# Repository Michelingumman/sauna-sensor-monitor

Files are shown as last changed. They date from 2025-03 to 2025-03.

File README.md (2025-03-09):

# 🔥 Sauna Monitoring System with ESP32




A smart monitoring system that tracks temperature and humidity in saunas, detects sessions automatically, and provides real-time visualization through an OLED display and optional web interface.

Custom PCB Board

## 🔍 Overview

This ESP32-based system provides comprehensive monitoring for saunas, automatically detecting when sessions begin and end based on temperature changes. The device displays real-time data on an OLED screen and can optionally connect to Blynk for remote monitoring.

## ✨ Features

### Time Synchronization
- Automatically syncs with NTP servers for accurate time display
- Shows current time in format: `Monday 01-13:00`

### Intelligent Session Detection
- Automatically detects sauna sessions when temperature rises from 20°C to 30°C within 15 minutes
- Tracks session duration and highest temperature
- Detects session end when temperature drops to 30% of peak temperature

### Real-time Monitoring
- Updates temperature and humidity readings every 2 seconds
- Shows current readings with icons
- Sauna Session active indicator

### Connectivity
- Wi-Fi connectivity for time synchronization
- Built-in web server with real-time dashboard
- OTA (Over-the-Air) update capability

## 🛠️ Hardware Requirements

### Components
- **ESP32 Development Board**: Any standard ESP32 board
- **SSD1306 OLED Display**: I2C interface
- **SHT2x Temperature/Humidity Sensor**: I2C interface

### Connections
| Component | ESP32 Pin |
|---|---|
| OLED SDA  | GPIO 6 |
| OLED SCL  | GPIO 7 |
| SHT2x | Same I2C bus |
| Power | 3.3V |

## 💻 Software Requirements

### Development Environment
- PlatformIO (recommended) or Arduino IDE
- Git (optional, for version control)

### Required Libraries
- Adafruit SSD1306
- Adafruit GFX
- SHT2x library
- AsyncTCP
- ESPAsyncWebServer
- ElegantOTA
- WiFi (built into ESP32 core)

## 📥 Installation & Setup

### 1. Clone or Download the Repository
```bash
git clone https://github.com/yourusername/sauna-sensor-monitor.git
cd sauna-sensor-monitor
```

### 2. Create secrets.h File
Create a file named `secrets.h` in the src directory with the following content:

```cpp
#ifndef SECRETS_H
#define SECRETS_H

#define WIFI_SSID "your_ssid"
#define WIFI_PASS "your_password"

#endif //SECRETS_H
```

> **⚠️ IMPORTANT**: Never commit the secrets.h file to version control. It contains sensitive information. Add it to .gitignore

### 3. Upload to ESP32
Using PlatformIO or Arduino IDE, compile and upload the code to your ESP32 board.

## ⚙️ How It Works

### Startup Sequence
1. ESP32 initializes and connects to WiFi using credentials from secrets.h
2. Synchronizes time with NTP servers and configures for correct timezone
3. Initializes the web server and OTA update capability
4. Begins monitoring temperature and humidity

### Main Operation Loop
- **Time Display**: Updates time at the top of the OLED once per minute
- **Sauna Detection**:
  - Monitors for temperature rise (20°C → 30°C within 15 minutes)
  - When detected, starts session timer and tracks peak temperature
  - Ends session when temperature drops below 30% of peak value
- **Data Visualization**:
  - Updates temperature and humidity readings every 10 seconds
  - Plots temperature as solid line and humidity as dotted line
  - Shows current values with icons

### Web Interface
- Provides a modern, responsive dashboard
- Displays real-time temperature and humidity
- Shows session status and historical data
- Enables OTA firmware updates
Sauna Monitor Display

## 🔧 Configuration

The project can be configured by modifying the following parameters in main.cpp:

```cpp
// OLED display settings
#define SCREEN_WIDTH 128        // OLED display width
#define SCREEN_HEIGHT 64        // OLED display height
#define OLED_RESET    -1        // Reset pin
#define SCREEN_ADDRESS 0x3C     // I2C address
#define SDA_PIN 6               // SDA pin
#define SCL_PIN 7               // SCL pin

// Timing settings
const unsigned long WIFI_RETRY_INTERVAL = 60000;  // WiFi retry (1 min)
const unsigned long WIFI_CONNECT_TIMEOUT = 10000; // WiFi timeout (10 sec)
```

---

Built with ❤️ for enhanced sauna experiences.

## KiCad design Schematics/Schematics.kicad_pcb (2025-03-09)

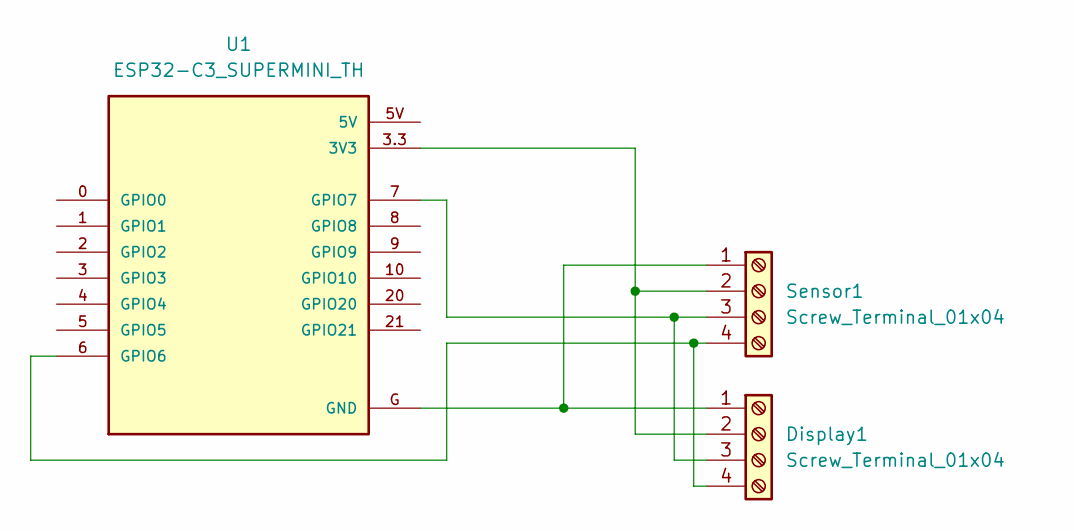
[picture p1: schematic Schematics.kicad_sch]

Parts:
Display1: Screw_Terminal_01x04; 128x64OLED
Sensor1: Screw_Terminal_01x04; TerminalBlock_Altech_AK300-4_P5.00mm
U1: ESP32-C3_SUPERMINI_TH; MODULE_ESP32-C3_SUPERMINI

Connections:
unnamed: Display1.1, Sensor1.1, U1.G (GND)
unnamed: Display1.2, Sensor1.2, U1.3.3 (3V3)
unnamed: Display1.3, Sensor1.3, U1.7 (GPIO7)
unnamed: Display1.4, Sensor1.4, U1.6 (GPIO6)

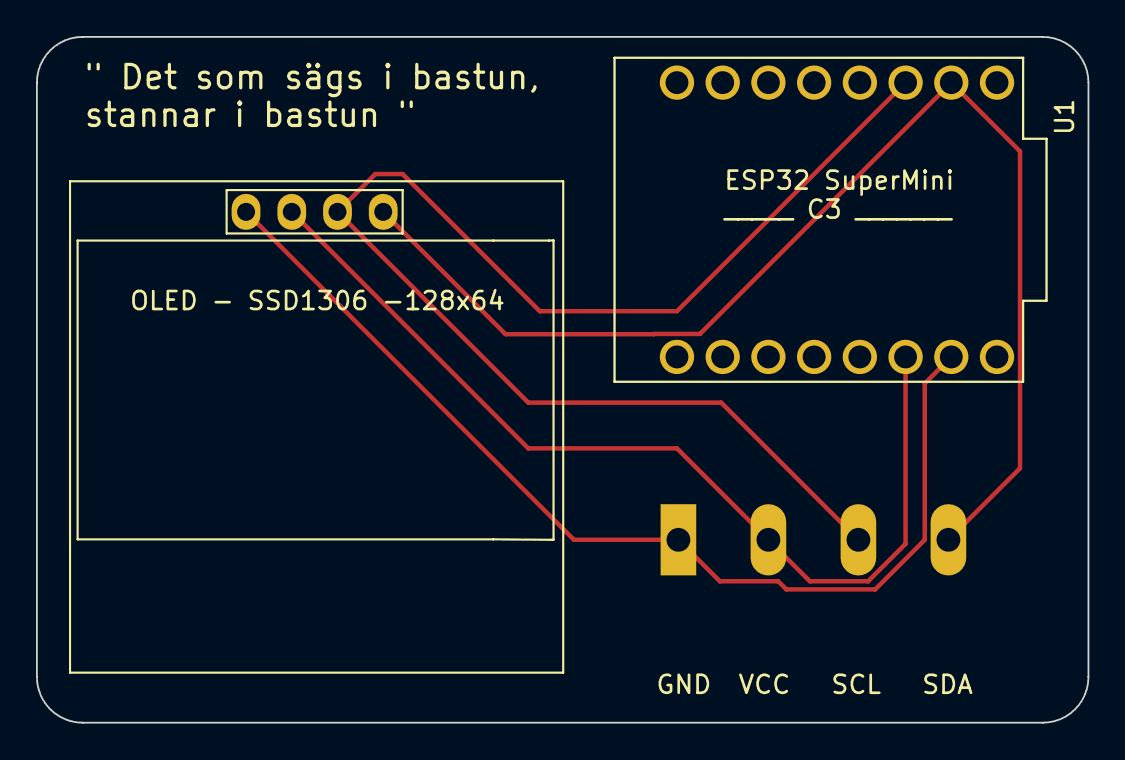
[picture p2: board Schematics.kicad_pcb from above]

Board: 2 copper layers, 58.4 x 38.1 mm, 3 parts (1 on the bottom side), 4 nets.

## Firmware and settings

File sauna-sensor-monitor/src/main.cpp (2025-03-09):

/*************************************************************
  Includes
*************************************************************/
#include <Arduino.h>
#include "images.h"         // For OLED display images
#include "secrets.h"         // Contains WIFI_SSID, WIFI_PASS, BLYNK_AUTH_TOKEN

#include <SPI.h>
#include <Wire.h>
#include <Adafruit_GFX.h>
#include <Adafruit_SSD1306.h>

#include "SHT2x.h"

#include <WiFi.h>
#include <WiFiClient.h>
#include <AsyncTCP.h>
#include <ESPAsyncWebServer.h>
#include <ElegantOTA.h>     // OTA update functionality

#include <time.h>            // For NTP time synchronization

/*************************************************************
  Definitions
*************************************************************/
#define DEMO_PIN  18            // Example pin to toggle (currently unused)

// OLED display settings
#define SCREEN_WIDTH 128        // OLED display width, in pixels
#define SCREEN_HEIGHT 64        // OLED display height, in pixels
#define OLED_RESET    -1        // Reset pin # (or -1 if sharing Arduino reset pin)
#define SCREEN_ADDRESS 0x3C     // I2C address for OLED display
#define SDA_PIN 6              // OLED SDA pin
#define SCL_PIN 7              // OLED SCL pin

/*************************************************************
  Global Objects
*************************************************************/
SHT2x sht;                      // For SHT temperature/humidity sensors
Adafruit_SSD1306 display(SCREEN_WIDTH, SCREEN_HEIGHT, &Wire, OLED_RESET);
AsyncWebServer server(80);      // Web server for OTA updates and file access

// State variables
bool pinState = false;          // Tracks toggling state
bool wifi_connected = false;
unsigned long last_wifi_attempt = 0;

// OTA update variables
unsigned long ota_progress_millis = 0;

// Timing settings
const unsigned long WIFI_RETRY_INTERVAL = 60000;  // Try to reconnect WiFi every minute
const unsigned long WIFI_CONNECT_TIMEOUT = 10000; // 10 seconds timeout for WiFi connection

// Sauna state variables
bool saunaActive = false;          // True if sauna session is active
bool crossed20   = false;          // True if we've crossed 20°C
unsigned long timeCrossed20 = 0;   // When we first crossed 20°C
unsigned long saunaStartTime = 0;  // When the sauna session started
float highestTempDuringSession = 0.0;

/*************************************************************
  FUNCTION Declarations
*************************************************************/
// OTA callback functions
void onOTAStart();
void onOTAProgress(size_t current, size_t final);
void onOTAEnd(bool success);

// WiFi and server functions
void check_wifi_connection();            // Check and attempt to reconnect WiFi
void setup_web_server();                 // Setup web server routes

// Display and sensor functions
void draw(float temperature, float humidity);
void printLocalTime(void);
float readTemperature(void);
float readHumidity(void);

// Application logic
void updateSaunaState(float currentTemp);

/*************************************************************
  OTA CALLBACK IMPLEMENTATIONS
*************************************************************/
/**
 * Called when OTA update begins
 */
void onOTAStart() {
  Serial.println("OTA update started!");
  // Show update status on display
  display.clearDisplay();
  display.setTextSize(1);
  display.setCursor(0, 0);
  display.println("OTA Update Started");
  display.display();
}

/**
 * Called periodically during OTA update process
 */
void onOTAProgress(size_t current, size_t final) {
  // Log progress every 1 second
  if (millis() - ota_progress_millis > 1000) {
    ota_progress_millis = millis();
    Serial.printf("OTA Progress: %u of %u bytes (%.1f%%)\n", 
                 current, final, (current * 100.0) / final);
    
    // Update progress on display
    display.clearDisplay();
    display.setTextSize(1);
    display.setCursor(0, 0);
    display.println("OTA Update Progress:");
    display.printf("%.1f%%\n", (current * 100.0) / final);
    
    // Draw progress bar
    int barWidth = (current * 100) / final;
    display.drawRect(14, 30, 100, 10, SSD1306_WHITE);
    display.fillRect(14, 30, barWidth, 10, SSD1306_WHITE);
    display.display();
  }
}

/**
 * Called when OTA update completes
 */
void onOTAEnd(bool success) {
  if (success) {
    Serial.println("OTA update completed successfully!");
    display.clearDisplay();
    display.setTextSize(1);
    display.setCursor(0, 0);
    display.println("OTA Update Complete!");
    display.println("Rebooting...");
    display.display();
  } else {
    Serial.println("Error during OTA update!");
    display.clearDisplay();
    display.setTextSize(1);
    display.setCursor(0, 0);
    display.println("OTA Update Failed!");
    display.display();
  }
}

/*************************************************************
  Web Server Setup
*************************************************************/
void setup_web_server() {
  // Root page with enhanced interface
  server.on("/", HTTP_GET, [](AsyncWebServerRequest *request){
    String html = "<!DOCTYPE html><html><head>";
    html += "<meta name='viewport' content='width=device-width, initial-scale=1'>";
    html += "<title>Sauna Sensor Monitor</title>";
    html += "<script src='https://cdn.jsdelivr.net/npm/chart.js'></script>";
    html += "<style>";
    html += "body { font-family: Arial, sans-serif; margin: 0; padding: 20px; text-align: center; background-color: #121212; color: #e0e0e0; }";
    html += "h1 { color: #ffffff; margin-top: 30px; font-weight: 300; letter-spacing: 1px; font-size: 1.8rem; }";
    html += ".btn { background-color: #4CAF50; border: none; color: white; padding: 15px 32px; ";
    html += "text-align: center; text-decoration: none; display: inline-block; font-size: 16px; margin: 20px 2px; cursor: pointer; border-radius: 8px; transition: all 0.3s; }";
    html += ".btn:hover { background-color: #3e8e41; transform: translateY(-2px); box-shadow: 0 4px 8px rgba(0,0,0,0.3); }";
    html += ".info { margin: 20px 0; padding: 15px; background-color: #1e1e1e; border-left: 6px solid #4CAF50; text-align: left; border-radius: 4px; color: #e0e0e0; }";
    html += ".data-container { display: flex; flex-wrap: wrap; justify-content: center; gap: 20px; margin: 30px 0; }";
    html += ".data-card { background-color: #1e1e1e; border-radius: 12px; padding: 20px; width: 180px; box-shadow: 0 4px 6px rgba(0,0,0,0.3); transition: transform 0.2s; }";
    html += ".data-card:hover { transform: translateY(-5px); box-shadow: 0 6px 10px rgba(0,0,0,0.4); }";
    
    // Style each card differently
    html += ".temp-card { border-top: 3px solid #ff6384; }";
    html += ".humidity-card { border-top: 3px solid #36a2eb; }";
    html += ".session-card { border-top: 3px solid #4CAF50; }";
    
    html += ".data-value { font-size: 32px; font-weight: bold; margin: 10px 0; color: #ffffff; }";
    html += ".data-label { color: #9e9e9e; font-size: 14px; }";
    html += ".chart-container { width: 100%; max-width: 800px; height: 400px; margin: 30px auto; padding: 20px; background-color: #1e1e1e; border-radius: 12px; box-shadow: 0 4px 6px rgba(0,0,0,0.3); }";
    html += "strong { color: #4CAF50; }";
    html += ".info p { margin: 8px 0; }";
    html += ".footer { margin-top: 30px; font-size: 12px; color: #9e9e9e; }";
    
    // Mobile responsive adjustments
    html += "@media (max-width: 768px) {";
    html += "  body { padding: 10px; }";
    html += "  h1 { font-size: 1.5rem; }";
    html += "  .info { margin: 15px 0; padding: 10px; }";
    html += "  .data-container { gap: 10px; margin: 15px 0; }";
    html += "  .data-card { width: calc(50% - 25px); padding: 15px; }";
    html += "  .data-value { font-size: 24px; }";
    html += "  .chart-container { height: 300px; padding: 10px; margin: 15px auto; }";
    html += "  .btn { padding: 12px 25px; font-size: 14px; }";
    html += "}";
    
    // Extra small screens
    html += "@media (max-width: 480px) {";
    html += "  .data-container { flex-direction: column; align-items: center; }";
    html += "  .data-card { width: 100%; max-width: 250px; }";
    html += "  .chart-container { height: 250px; }";
    html += "}";
    
    html += "</style>";
    
    // Add dark mode Chart.js config
    html += "<script>";
    html += "Chart.defaults.color = '#e0e0e0';";
    html += "Chart.defaults.borderColor = '#303030';";
    html += "</script>";
    
    html += "</head><body>";
    html += "<h1>Sauna Sensor Monitor</h1>";
    
    html += "<div class='info'>";
    html += "<p><strong>Device:</strong> ESP32 (Sauna-Sensor)</p>";
    html += "<p><strong>IP Address:</strong> " + WiFi.localIP().toString() + "</p>";
    html += "</div>";
    
    // Data cards for current readings
    html += "<div class='data-container'>";
    
    // Temperature card
    html += "<div class='data-card temp-card'>";
    html += "<div class='data-label'>Temperature</div>";
    html += "<div class='data-value' id='temp-value'>--</div>";
    html += "<div class='data-label'>°C</div>";
    html += "</div>";
    
    // Humidity card
    html += "<div class='data-card humidity-card'>";
    html += "<div class='data-label'>Humidity</div>";
    html += "<div class='data-value' id='humidity-value'>--</div>";
    html += "<div class='data-label'>%</div>";
    html += "</div>";
    
    // Session time card
    html += "<div class='data-card session-card'>";
    html += "<div class='data-label'>Session Time</div>";
    html += "<div class='data-value' id='session-time'>--</div>";
    html += "<div class='data-label'>minutes</div>";
    html += "</div>";
    
    html += "</div>";
    
    // Graph container
    html += "<div class='chart-container'>";
    html += "<canvas id='sensorChart'></canvas>";
    html += "</div>";
    
    html += "<a href='/update' class='btn'>OTA Updates</a>";
    
    // JavaScript to fetch data and update the UI
    html += "<script>";
    html += "let chart;";
    html += "function fetchData() {";
    html += "  console.log('Fetching data from /data endpoint...');";
    html += "  fetch('/data', { cache: 'no-store' })"; // Add no-store to prevent caching
    html += "    .then(response => {";
    html += "      console.log('Response status:', response.status);";
    html += "      if (!response.ok) {";
    html += "        throw new Error('Network response error: ' + response.status);";
    html += "      }";
    html += "      return response.text();"; // First get as text
    html += "    })";
    html += "    .then(text => {";
    html += "      console.log('Raw response:', text);"; // Log the raw text
    html += "      // Parse JSON manually to avoid potential issues";
    html += "      try {";
    html += "        return JSON.parse(text);";
    html += "      } catch (e) {";
    html += "        console.error('JSON parse error:', e, 'for text:', text);";
    html += "        throw new Error('Failed to parse JSON response');";
    html += "      }";
    html += "    })";
    html += "    .then(data => {";
    html += "      console.log('Parsed data:', data);"; // Debug log
    
    html += "      // Get DOM elements once";
    html += "      const tempElement = document.getElementById('temp-value');";
    html += "      const humElement = document.getElementById('humidity-value');";
    html += "      const sessionElement = document.getElementById('session-time');";
    
    html += "      // Check if elements exist";
    html += "      if (!tempElement || !humElement || !sessionElement) {";
    html += "        console.error('Could not find one or more DOM elements');";
    html += "        return;";
    html += "      }";
    
    html += "      // Update temperature";
    html += "      if (data.temperature !== undefined) {";
    html += "        try {";
    html += "          const tempVal = Number(data.temperature);";
    html += "          tempElement.textContent = tempVal.toFixed(1);";
    html += "          console.log('Updated temperature to:', tempVal.toFixed(1));";
    html += "        } catch (e) {";
    html += "          console.error('Error setting temperature:', e);";
    html += "          tempElement.textContent = 'Error';";
    html += "        }";
    html += "      }";
    
    html += "      // Update humidity";
    html += "      if (data.humidity !== undefined) {";
    html += "        try {";
    html += "          const humVal = Number(data.humidity);";
    html += "          humElement.textContent = Math.round(humVal);";
    html += "          console.log('Updated humidity to:', Math.round(humVal));";
    html += "        } catch (e) {";
    html += "          console.error('Error setting humidity:', e);";
    html += "          humElement.textContent = 'Error';";
    html += "        }";
    html += "      }";
    
    html += "      // Update session time";
    html += "      if (data.sessionTime !== undefined) {";
    html += "        try {";
    html += "          sessionElement.textContent = data.sessionTime;";
    html += "          console.log('Updated session time to:', data.sessionTime);";
    html += "        } catch (e) {";
    html += "          console.error('Error setting session time:', e);";
    html += "          sessionElement.textContent = '0';";
    html += "        }";
    html += "      }";
    
    html += "      // Update chart if we have valid data";
    html += "      if (data.tempHistory && data.humHistory && data.labels) {";
    html += "        updateChart(data);";
    html += "      }";
    html += "    })";
    html += "    .catch(error => {";
    html += "      console.error('Fetch error:', error);";
    html += "    });";
    html += "}";
    
    html += "function updateChart(data) {";
    html += "  if (!chart) {";
    html += "    const ctx = document.getElementById('sensorChart').getContext('2d');";
    html += "    chart = new Chart(ctx, {";
    html += "      type: 'line',";
    html += "      data: {";
    html += "        labels: data.labels,";
    html += "        datasets: [";
    html += "          {";
    html += "            label: 'Temperature (°C)',";
    html += "            data: data.tempHistory,";
    html += "            borderColor: '#ff6384',";
    html += "            backgroundColor: 'rgba(255, 99, 132, 0.2)',";
    html += "            borderWidth: 2,";
    html += "            pointRadius: 3,";
    html += "            tension: 0.3";
    html += "          },";
    html += "          {";
    html += "            label: 'Humidity (%)',";
    html += "            data: data.humHistory,";
    html += "            borderColor: '#36a2eb',";
    html += "            backgroundColor: 'rgba(54, 162, 235, 0.2)',";
    html += "            borderWidth: 2,";
    html += "            pointRadius: 3,";
    html += "            tension: 0.3";
    html += "          }";
    html += "        ]";
    html += "      },";
    html += "      options: {";
    html += "        responsive: true,";
    html += "        maintainAspectRatio: false,";
    html += "        plugins: {";
    html += "          legend: {";
    html += "            labels: {";
    html += "              color: '#e0e0e0',";
    html += "              font: {";
    html += "                size: 12";
    html += "              },";
    html += "              boxWidth: 12";
    html += "            },";
    html += "            position: window.innerWidth < 768 ? 'bottom' : 'top'";
    html += "          },";
    html += "          tooltip: {";
    html += "            mode: 'index',";
    html += "            intersect: false,";
    html += "            backgroundColor: 'rgba(0,0,0,0.7)'";
    html += "          }";
    html += "        },";
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
void loop() {
  static unsigned long lastDisplayUpdate = 0;
  static unsigned long lastSerialOutput = 0;
  static unsigned long lastWifiCheck = 0;
  unsigned long currentMillis = millis();
  
  // Process OTA updates if WiFi connected
  if (wifi_connected) {
    ElegantOTA.loop();
  }
  
  // Check and reconnect WiFi periodically if needed
  if (currentMillis - lastWifiCheck >= WIFI_RETRY_INTERVAL) {
    lastWifiCheck = currentMillis;
    check_wifi_connection();
  }
  
  // Read sensor data and update display
  if (currentMillis - lastDisplayUpdate >= 2000) {
    float currentTemp = readTemperature();
    float currentHum = readHumidity();
    
    // Update sauna state logic based on temperature
    updateSaunaState(currentTemp);
    
    // Update display
    lastDisplayUpdate = currentMillis;
    draw(currentTemp, currentHum);
    
    // Print minimal status info to serial (once per minute)
    if (currentMillis - lastSerialOutput >= 60000) {
      lastSerialOutput = currentMillis;
      
      // Get current time
      struct tm timeinfo;
      if (getLocalTime(&timeinfo)) {
        char timeStr[20];
        strftime(timeStr, sizeof(timeStr), "%H:%M:%S", &timeinfo);
        
        // Print status in a clean, concise format
        Serial.printf("[%s] Temp: %.1f°C | Humidity: %d%% | WiFi: %s\n", 
                     timeStr, 
                     currentTemp, 
                     (int)currentHum,
                     wifi_connected ? "Connected" : "Disconnected");
                     
        if (saunaActive) {
          unsigned long sessionMinutes = (millis() - saunaStartTime) / 60000;
          Serial.printf("        Sauna active for %lu minutes\n", sessionMinutes);
        }
      }
    }
  }
  
  // Small delay to prevent CPU hogging
  delay(25);
}

void printLocalTime(void) {
    
  struct tm timeinfo;
  if (!getLocalTime(&timeinfo)) {
    Serial.println("Failed to obtain time");
  } else {
    Serial.println(&timeinfo, "Current time: %A, %B %d %Y %H:%M:%S");
  }

}

// Implement actual temperature reading from SHT2x sensor
float readTemperature() { 
  // Read from SHT2x sensor
  sht.read();
  float temp = sht.getTemperature();
  
  // Check if reading is valid (not NaN or infinite)
  if (isnan(temp) || isinf(temp)) {
    Serial.println("Error reading temperature from sensor!");
    // Return a fallback value
    return 25.0;
  }
  
  // Serial.printf("Temperature read: %.2f°C\n", temp);
  return temp;
}

// Implement actual humidity reading from SHT2x sensor
float readHumidity() {
  // Read from SHT2x sensor
  sht.read();
  float humidity = sht.getHumidity();
  
  // Check if reading is valid (not NaN or infinite)
  if (isnan(humidity) || isinf(humidity) || humidity < 0 || humidity > 100) {
    Serial.println("Error reading humidity from sensor!");
    // Return a fallback value
    return 50.0;
  }
  
  // Serial.printf("Humidity read: %.2f%%\n", humidity);
  return humidity;
}

/*************************************************************
  updateSaunaState(currentTemp)
  - 1) If temperature rises from 20°C to 30°C within 15 mins => sauna on
  - 2) Track session time
  - 3) If temp drops below 30% of highest recorded => sauna off
*************************************************************/
void updateSaunaState(float currentTemp) {
  unsigned long now = millis();

  // If sauna is NOT active, watch for 20→30°C jump within 15 min
  if (!saunaActive) {
    // Check crossing 20°C
    if (!crossed20 && currentTemp >= 20.0) {
      crossed20 = true;
      timeCrossed20 = now;
    }
    // If we crossed 20°C, check if we've reached 30°C
    if (crossed20 && currentTemp >= 30.0) {
      // Did it happen within 15 minutes (900,000 ms)?
      if ((now - timeCrossed20) <= 900000UL) {
        saunaActive = true;
        saunaStartTime = now;
        highestTempDuringSession = currentTemp;
        Serial.println("Sauna session started!");
      }
      // Reset the 20°C flag whether or not it met the 15-min condition
      crossed20 = false;
    }
  }
  // If sauna is active, track highest temp and check for cooldown
  else {
    if (currentTemp > highestTempDuringSession) {
      highestTempDuringSession = currentTemp;
    }
    // If temp falls to 30% of highest recorded, consider sauna off
    float offThreshold = 0.30 * highestTempDuringSession;
    if (currentTemp <= offThreshold) {
      saunaActive = false;
      unsigned long sessionDuration = now - saunaStartTime;
      Serial.print("Sauna session ended. Duration (ms): ");
      Serial.println(sessionDuration);

      // Reset tracking
      highestTempDuringSession = 0.0;
      crossed20 = false;
    }
  }
}

void draw(float temperature, float humidity) {
  display.clearDisplay();
  
  // Draw border
  display.drawRect(0, 0, display.width(), display.height(), SSD1306_WHITE);
  
  // Show WiFi status icon in top right corner
  if (!wifi_connected) {
    display.drawBitmap(display.width() - 18, 2, NO_NETWORK_ICON, 16, 16, SSD1306_WHITE);
  }
  
  // Temperature section - moved higher up
  display.drawBitmap(8, 6, TEMP_ICON, 16, 16, SSD1306_WHITE);
  display.setTextSize(2);
  display.setCursor(28, 6);
  display.print(temperature, 1);
  display.setTextSize(2);
  display.print(" C");
  
  // Separator line
  display.drawLine(0, 28, display.width(), 28, SSD1306_WHITE);
  
  // Humidity section - moved higher up
  display.drawBitmap(8, 34, DROP_ICON, 16, 16, SSD1306_WHITE);
  display.setTextSize(2);
  display.setCursor(28, 34);
  display.print(int(humidity));
  display.print(" %");
  
  // Show sauna session info in a dedicated bottom area
  if (saunaActive) {
    // Bottom status bar with enough clearance from humidity reading
    display.drawLine(0, 54, display.width(), 54, SSD1306_WHITE);
    
    display.setTextSize(1);
    display.setCursor(3, 56);
    display.print("SAUNA ON ");
    
    // Calculate session time
    unsigned long sessionMin = (millis() - saunaStartTime) / 60000;
    unsigned long sessionSec = ((millis() - saunaStartTime) % 60000) / 1000;
    
    display.print(sessionMin);
    display.print(":");
    if (sessionSec < 10) display.print("0");
    display.print(sessionSec);
  }

    display.display();
}

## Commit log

2025-02-25 Update OLED display I2C address to 0x70
2025-03-03 Refactor loop logic to improve time display and sensor data logging
2025-03-09 importing KiCad Files
    [Schematics-B_Cu.gbr, Schematics-B_Mask.gbr, Schematics-B_Paste.gbr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]
